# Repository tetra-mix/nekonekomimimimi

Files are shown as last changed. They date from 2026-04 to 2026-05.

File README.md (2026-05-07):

# ねこねこみみみみ
## 概要
VRCとの連携を目的として、市販されている猫耳カチューシャに取り付けられるハプティクスデバイスを作成する。ケーブル部分には、3Dプリンターで作成したケーブルチェーンを用いる。senseshift-hardwareというOSSプロジェクトを参考にしながら作成する。

## 参考
[自作ハプティクスベストを作ってみた。｜KirisameNanoha](https://note.com/kirisamenanoha/n/n8a3842eb5d57)
[GitHub - senseshift/senseshift-hardware: Hardware schematics to build haptic-feedback devices](https://github.com/senseshift/senseshift-hardware)
[OSC](https://note.com/kirisamenanoha/n/n18400ababb78?app_launch=false)
## 予備知識

### ハプティクスモーターについて
ERM 偏心回転質量
* PWAで制御
	種類
	* コイン型
	* 円筒型
	* コア型

LRA 線形共振
* 注意：ドライバが必要
	種類
	* コイン型
	* バー型
	* Y軸(平行)
	* Z軸(垂直)

## 案
### 案１
* マイコン esp32系
	* xiao esp32s3 or c6
* ドライバ DRV2605 x2
* LRAコイン型(Z軸)を直線に複数配置
* 左右の耳の下に3つずつ(計6つ)
* 電源をどうするかは検討
	* リポバッテリー？
	* 最初はモバイルバッテリーかな
→LRAが入手しづらい

### 案２ →採用
 * マイコン esp32系
	* xiao esp32s3 or c6
* ERMコイン型を直線に複数配置
* 左右の耳の下に3つずつ(計6つ)
* MOSFET x6
* 電源をどうするかは検討
	* リポバッテリー？
	* 最初はモバイルバッテリー

## 回路図
1チャンネル分
```
                 VMOTOR (+3.0V～4.2V)
                        |
                        |
                    +---+---+
                    |  ERM  |
                    |Motor  |
                    +---+---+
                        |
                        +-------------------+
                        |                   |
                        |                 |<| D1
                        |            SS14 / 1N5819
                        |                 | |
                        |                   |
                        |                   +---- VMOTOR
                        |
                      Drain
                    Q1 N-MOSFET ---- Gate
                      Source
                        |
                       GND

XIAO GPIO PWM ----[100Ω]---- Gate
                         |
                       [100kΩ]
                         |
                        GND
```

MOSFETをどれだけON・OFFするかによって強さを決める

## 配置図
```
        [前（おでこ）]

   左側               右側
   ●──●──●       ●──●──●
   前  中  後       前  中  後

        [後（後頭部）]
```

## 部品
秋月電子の場合

| 品名 | 型番 |  個数 | 値段 | 購入リンク |
| --- | --- | --: | ----: | --- |
| DMOSトランジスタアレイ | TBD62003APG | 1 | 100 | [109943](https://akizukidenshi.com/catalog/g/g109943/) |
| ミニ振動モーター | (記載なし / 秋月ミニ振動モーター) | 6 | 200 | [16777](https://akizukidenshi.com/catalog/g/g116777/)  |
| マイコンボード | XIAO ESP32S3 | 1 | 1,480 | [118078](https://akizukidenshi.com/catalog/g/g118078/) |
| ショットキーダイオード | 1S4 | 1 | 140 | [116384](https://akizukidenshi.com/catalog/g/g116384/) |
| 電解コンデンサ | 1000µF（耐圧10V〜） | 1 | 20 | [108424](https://akizukidenshi.com/catalog/g/g108424/) |
| LDO 3.3V1A | BA033CC0T | 1 | 100 | [113675](https://akizukidenshi.com/catalog/g/g113675/) |

合計3220円

振動モーターはアリエクで買ってもいいかも？

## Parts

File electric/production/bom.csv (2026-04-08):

Designator | Footprint | Quantity | Value | LCSC Part #
C1 | CP_Radial_D10.0mm_P5.00mm | 1 | 1000u
D1, D2, D3, D4, D5, D6, D7 | D_DO-35_SOD27_P7.62mm_Horizontal | 7 | D
H1, H2, H3, H4 | MountingHole_2.2mm_M2 | 4 | MountingHole
J1, J2, J3, J4, J5, J6, J7 | JST_XH_B2B-XH-A_1x02_P2.50mm_Vertical | 7 | Conn_01x02_Socket
J8 | PinHeader_1x06_P2.54mm_Vertical | 1 | Conn_01x06
R1, R2, R3, R4, R5, R6, R7 | resistor_0207_10 | 7 | 100
R10, R11, R12, R13, R14, R8, R9 | resistor_0207_10 | 7 | 100k
U1 | XIAO-ESP32-C6-DIP | 1 | XIAO-ESP32-C3-DIP
U2 | DIP-16_W7.62mm_Socket | 1 | TBD62003APG
U3 | PinHeader_1x03_P2.54mm_Vertical | 1 | BP5293

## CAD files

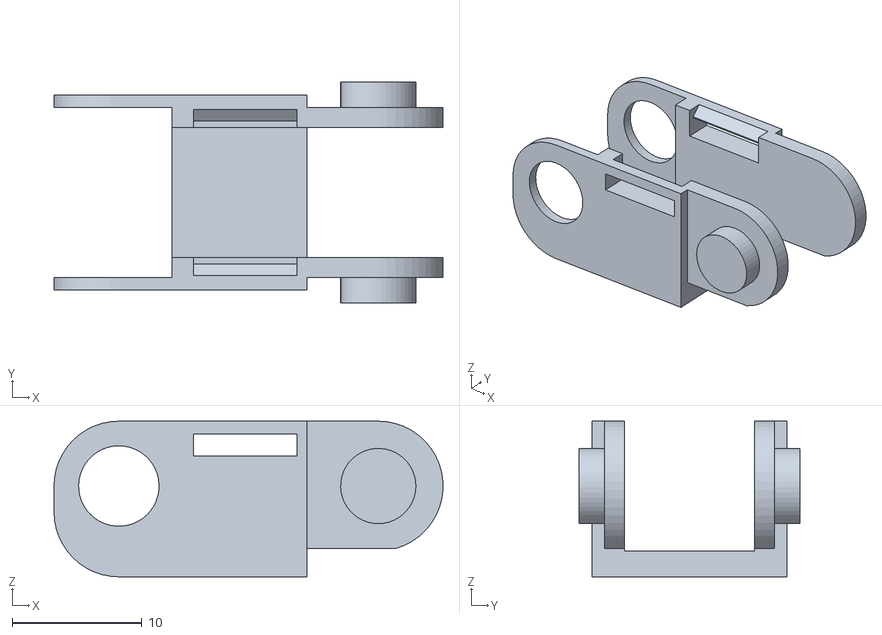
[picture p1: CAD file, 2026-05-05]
3Dmodel/vr2.0_CableChane_Original.stl
30.0 x 17.0 x 12.0

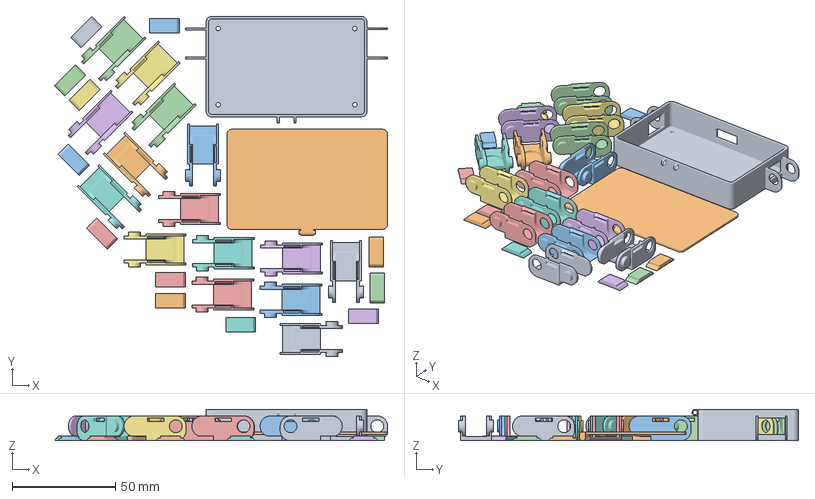
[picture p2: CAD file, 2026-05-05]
3Dmodel/vr1.1_CableChane.3mf
161.0 x 164.3 x 15.2 mm
PCBCase_base.stl
PCBCase_top.stl
CableChane_Original.stl x 9
CableChane_Motor.stl x 6
CaseTop.stl x 12

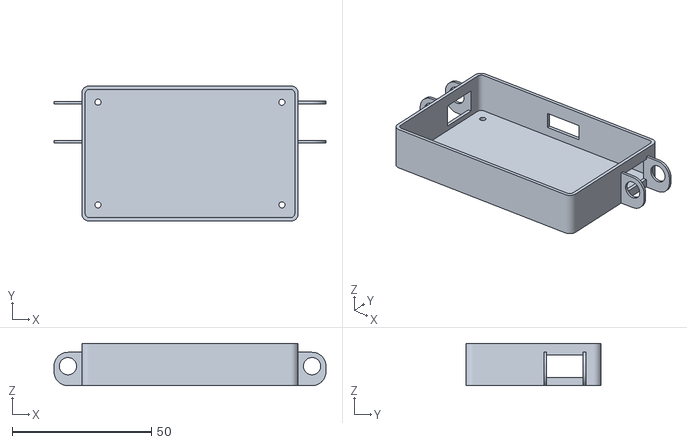
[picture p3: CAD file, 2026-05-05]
3Dmodel/vr2.0_PCBCase_base.stl
97.6 x 48.4 x 15.2

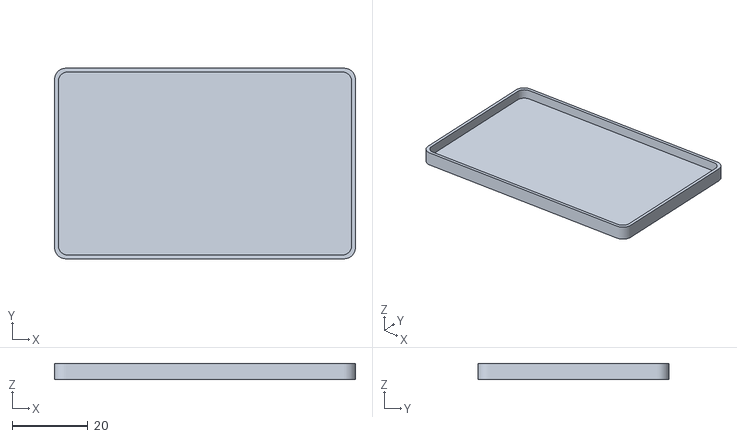
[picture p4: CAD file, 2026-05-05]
3Dmodel/vr2.0_PCBCase_top.stl
79.7 x 50.4 x 4.30

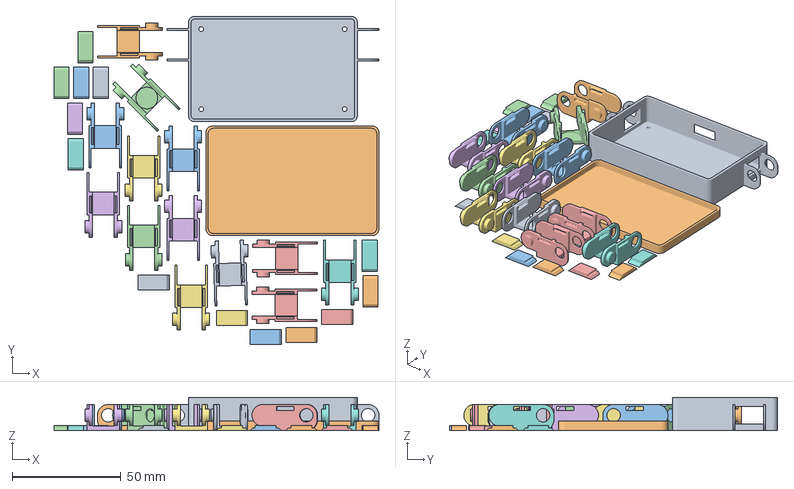
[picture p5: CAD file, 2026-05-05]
3Dmodel/vr2.0_CableChane_Motor.3mf
149.6 x 151.0 x 15.2 mm
vr2.0_PCBCase_base.stl
vr2.0_PCBCase_top.stl
vr2.0_CableChane_Motor.stl x 7
vr2.0_CableChane_Original.stl x 6
vr1.1_ChaneTop.stl x 13

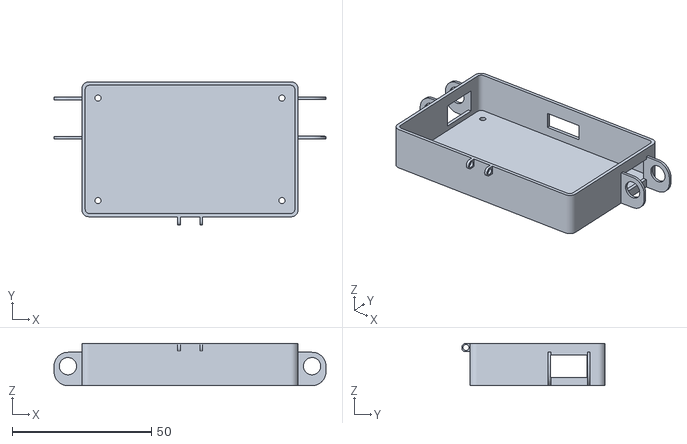
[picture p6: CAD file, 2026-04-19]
3Dmodel/vr1.0_PCBCase_base.stl
97.6 x 51.4 x 15.2

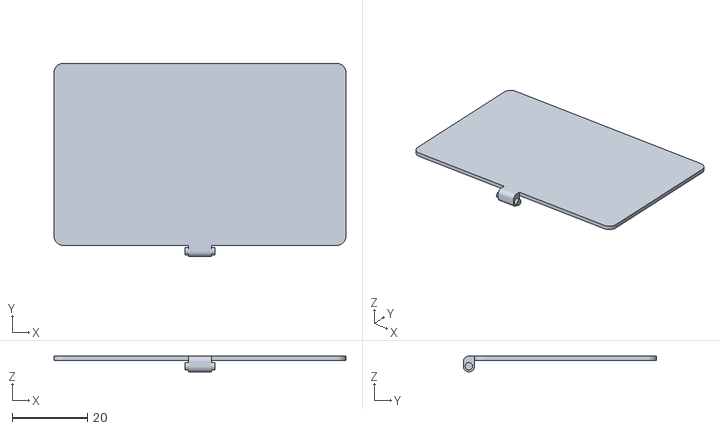
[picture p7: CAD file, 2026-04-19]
3Dmodel/vr1.0_PCBCase_top.stl
77.7 x 51.4 x 4.20

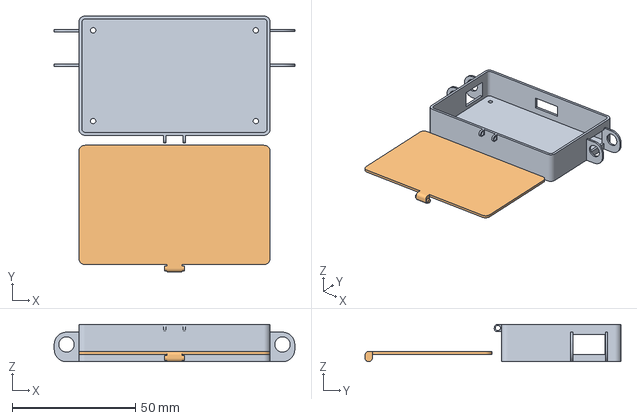
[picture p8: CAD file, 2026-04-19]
3Dmodel/vr1.0_PCBCase.3mf
97.6 x 103.9 x 15.2 mm
PCBCase_base.stl
PCBCase_top.stl

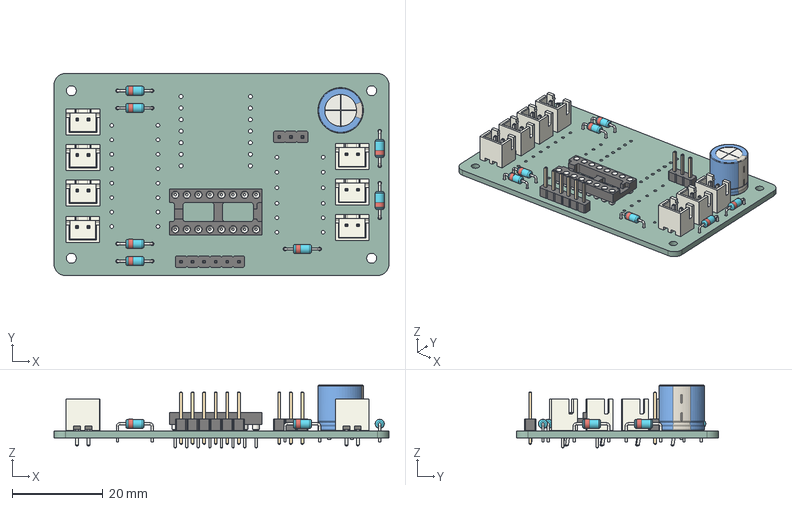
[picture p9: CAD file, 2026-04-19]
3Dmodel/PCB.step
73.7 x 44.5 x 13.8 mm
D_DO-35_SOD27_P7.62mm_Horizontal x 7
PinHeader_1x06_P2.54mm_Vertical
JST_XH_B2B-XH-A_1x02_P2.50mm_Vertical x 7
PinHeader_1x03_P2.54mm_Vertical
DIP-16_W7.62mm_Socket
CP_Radial_D10.0mm_P5.00mm
nekonekomimimimi_PCB

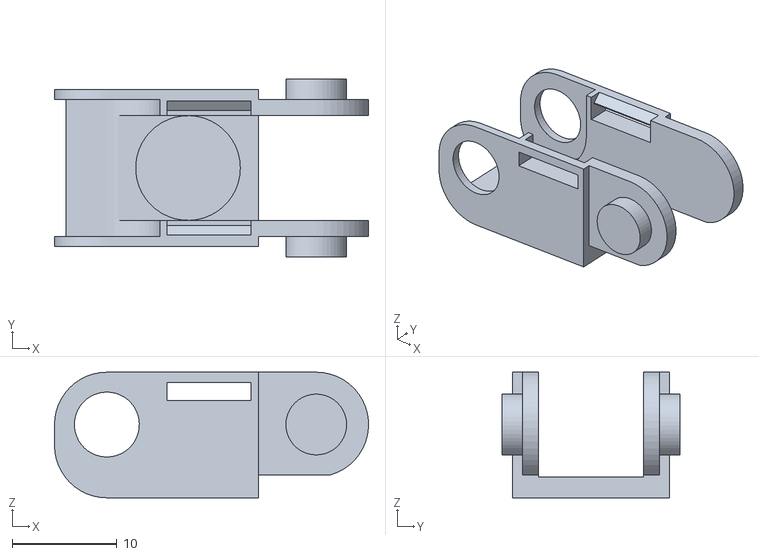
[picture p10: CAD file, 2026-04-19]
3Dmodel/vr1.1_CableChane_Motor.stl
30.0 x 17.0 x 12.0

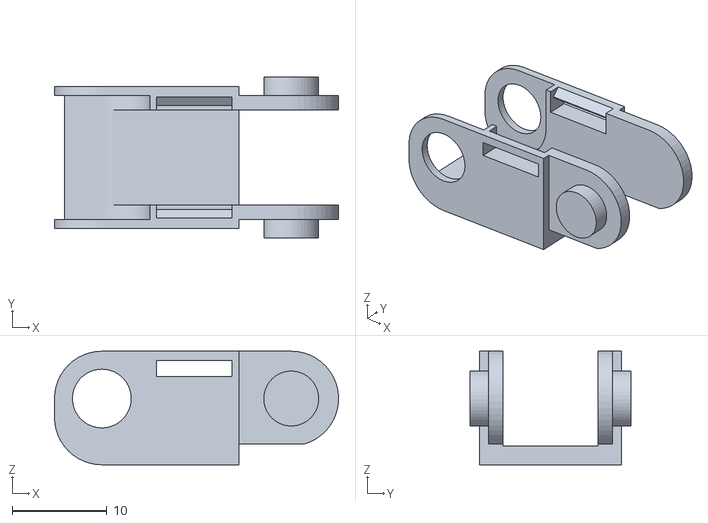
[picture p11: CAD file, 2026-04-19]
3Dmodel/vr1.1_CableChane_Original.stl
30.0 x 17.0 x 12.0

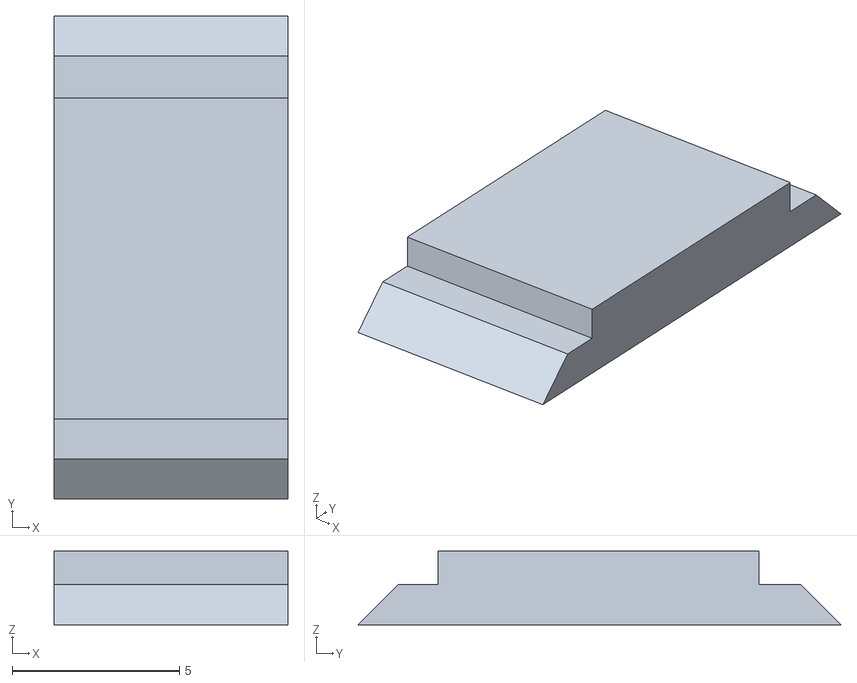
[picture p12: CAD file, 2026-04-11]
3Dmodel/vr1.1_ChaneTop.stl
7.00 x 14.4 x 2.20

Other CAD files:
3Dmodel/vr1.1_CableChane.gcode.3mf
3Dmodel/vr1.0_PCBCase.gcode.3mf
3Dmodel/vr2.0_CableChane_Motor.stl

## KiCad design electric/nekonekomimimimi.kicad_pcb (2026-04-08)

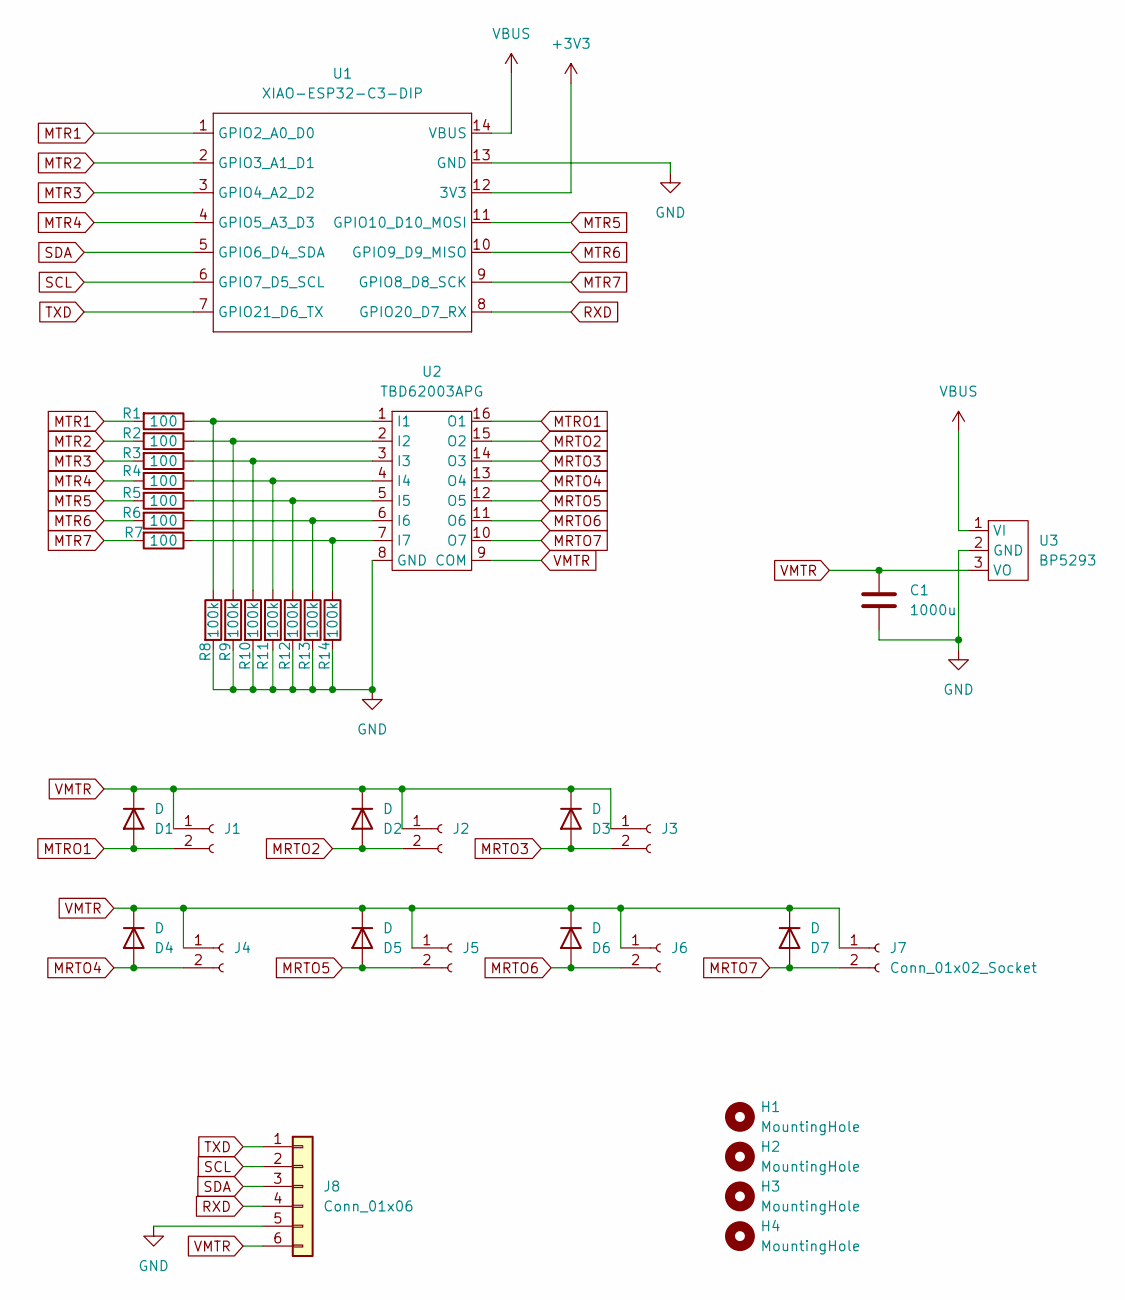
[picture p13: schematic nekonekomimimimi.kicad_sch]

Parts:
C1: 1000u; CP_Radial_D10.0mm_P5.00mm
D1, D2, D3, D4, D5, D6, D7: D; D_DO-35_SOD27_P7.62mm_Horizontal
H1, H2, H3, H4: MountingHole; MountingHole_2.2mm_M2
J1, J2, J3, J4, J5, J6, J7: Conn_01x02_Socket; JST_XH_B2B-XH-A_1x02_P2.50mm_Vertical
J8: Conn_01x06; PinHeader_1x06_P2.54mm_Vertical
R1, R2, R3, R4, R5, R6, R7: 100; resistor_0207_10
R8, R9, R10, R11, R12, R13, R14: 100k; resistor_0207_10
U1: XIAO-ESP32-C3-DIP; XIAO-ESP32-C6-DIP
U2: TBD62003APG; DIP-16_W7.62mm_Socket
U3: BP5293; PinHeader_1x03_P2.54mm_Vertical

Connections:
+3V3: U1.12 (3V3)
GND: C1.2, J8.5, R8.2, R9.2, R10.2, R11.2, R12.2, R13.2, R14.2, U1.13 (GND), U2.8 (GND), U3.2 (GND)
MRTO2: D2.2 (A), J2.2, U2.15 (O2)
MRTO3: D3.2 (A), J3.2, U2.14 (O3)
MRTO4: D4.2 (A), J4.2, U2.13 (O4)
MRTO5: D5.2 (A), J5.2, U2.12 (O5)
MRTO6: D6.2 (A), J6.2, U2.11 (O6)
MRTO7: D7.2 (A), J7.2, U2.10 (O7)
MTR1: R1.2, U1.1 (GPIO2_A0_D0)
MTR2: R2.2, U1.2 (GPIO3_A1_D1)
MTR3: R3.2, U1.3 (GPIO4_A2_D2)
MTR4: R4.2, U1.4 (GPIO5_A3_D3)
MTR5: R5.2, U1.11 (GPIO10_D10_MOSI)
MTR6: R6.2, U1.10 (GPIO9_D9_MISO)
MTR7: R7.2, U1.9 (GPIO8_D8_SCK)
MTRO1: D1.2 (A), J1.2, U2.16 (O1)
unnamed: R1.1, R8.1, U2.1 (I1)
unnamed: R2.1, R9.1, U2.2 (I2)
unnamed: R3.1, R10.1, U2.3 (I3)
unnamed: R4.1, R11.1, U2.4 (I4)
unnamed: R5.1, R12.1, U2.5 (I5)
unnamed: R6.1, R13.1, U2.6 (I6)
unnamed: R7.1, R14.1, U2.7 (I7)
RXD: J8.4, U1.8 (GPIO20_D7_RX)
SCL: J8.2, U1.6 (GPIO7_D5_SCL)
SDA: J8.3, U1.5 (GPIO6_D4_SDA)
TXD: J8.1, U1.7 (GPIO21_D6_TX)
VBUS: U1.14 (VBUS), U3.1 (VI)
VMTR: C1.1, D1.1 (K), D2.1 (K), D3.1 (K), D4.1 (K), D5.1 (K), D6.1 (K), D7.1 (K), J1.1, J2.1, J3.1, J4.1, J5.1, J6.1, J7.1, J8.6, U2.9 (COM), U3.3 (VO)

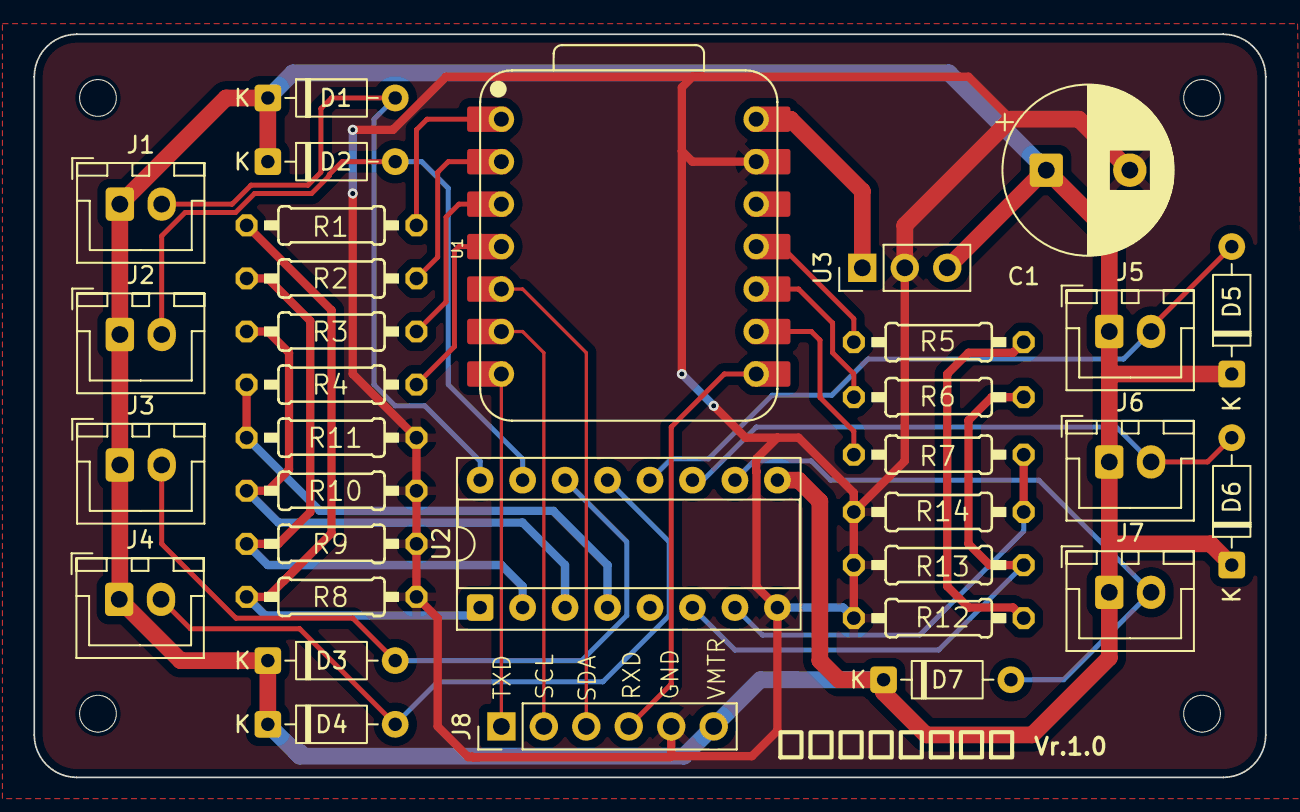
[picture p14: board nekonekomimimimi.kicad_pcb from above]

Board: 2 copper layers, 73.7 x 44.5 mm, 37 parts (0 on the bottom side), 28 nets.

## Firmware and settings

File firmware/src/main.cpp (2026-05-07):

#include <Arduino.h>
#include <ArduinoOSCWiFi.h>
#include <WiFi.h>

#define ESP_WM_LITE_DEBUG_OUTPUT Serial
#define _ESP_WM_LITE_LOGLEVEL_ 2
// The board pins used for the motors overlap typical status LED defaults.
#define USE_LED_BUILTIN false
// Accept a single Wi-Fi credential pair in the config portal.
#define REQUIRE_ONE_SET_SSID_PW true

#include <ESP_WiFiManager_Lite.h>
#include "motor_control.h"
#include "osc_router.h"

bool LOAD_DEFAULT_CONFIG_DATA = false;

ESP_WM_LITE_Configuration defaultConfig = {
  "ESP32",
  {
    {"", ""},
    {"", ""}
  },
  "hard-osc",
  0
};

uint32_t getChipID() {
  uint64_t chipId64 = 0;

  for (int i = 0; i < 6; ++i) {
    chipId64 |= (((uint64_t)ESP.getEfuseMac() >> (40 - (i * 8))) & 0xff) << (i * 8);
  }

  return static_cast<uint32_t>(chipId64 & 0xFFFFFF);
}

uint32_t getChipOUI() {
  uint64_t chipId64 = 0;

  for (int i = 0; i < 6; ++i) {
    chipId64 |= (((uint64_t)ESP.getEfuseMac() >> (40 - (i * 8))) & 0xff) << (i * 8);
  }

  return static_cast<uint32_t>(chipId64 >> 24);
}

namespace {

constexpr int kOscRecvPort = 9001;
constexpr char kHostName[] = "hard-osc";
constexpr char kConfigPortalSsid[] = "hard-osc-setup";
constexpr char kConfigPortalPassword[] = "00000000";

ESP_WiFiManager_Lite* wifiManager = nullptr;
bool lastConfigMode = false;

void setupWiFiManager() {
  wifiManager = new ESP_WiFiManager_Lite();
  wifiManager->setConfigPortal(kConfigPortalSsid, kConfigPortalPassword);
  wifiManager->setConfigPortalChannel(0);
  wifiManager->begin(kHostName);

  if (WiFi.status() == WL_CONNECTED) {
    Serial.print("[wifi] connected, STA IP: ");
    Serial.println(WiFi.localIP());
  } else if (wifiManager->isConfigMode()) {
    Serial.print("[wifi] config portal active: ");
    Serial.println(kConfigPortalSsid);
  }
}

void updateWiFiManager() {
  wifiManager->run();

  const bool configMode = wifiManager->isConfigMode();
  if (configMode != lastConfigMode) {
    lastConfigMode = configMode;

    if (configMode) {
      Serial.print("[wifi] entered config portal: ");
      Serial.println(kConfigPortalSsid);
    } else if (WiFi.status() == WL_CONNECTED) {
      Serial.print("[wifi] connected, STA IP: ");
      Serial.println(WiFi.localIP());
    }
  }
}

}  // namespace

void setup() {
  Serial.begin(115200);
  delay(200);

  initMotors();
  stopAllMotors();

  setupWiFiManager();
  subscribeOscRoutes(kOscRecvPort);

  Serial.printf("[osc] listening on UDP %d\n", kOscRecvPort);
  Serial.println("[osc] routes: /motor/1..7, /motor/all, /motor/stop");
}

void loop() {
  updateWiFiManager();
  OscWiFi.update();
  updateMotorFailsafe();
  delay(0);
}

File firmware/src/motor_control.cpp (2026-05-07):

#include "motor_control.h"

#include <Arduino.h>
#include <esp32-hal-ledc.h>

namespace {

constexpr unsigned long kOscTimeoutMs = 1000;
constexpr uint32_t kPwmFrequencyHz = 10000;
constexpr uint8_t kPwmResolutionBits = 8;
constexpr uint32_t kPwmMaxDuty = (1u << kPwmResolutionBits) - 1u;

constexpr int kMotorPins[kMotorCount] = {
  2,   // ch1 -> GPIO2 / D0
  3,   // ch2 -> GPIO3 / D1
  4,   // ch3 -> GPIO4 / D2
  5,   // ch4 -> GPIO5 / D3
  10,  // ch5 -> GPIO10 / D10
  9,   // ch6 -> GPIO9 / D9
  8    // ch7 -> GPIO8 / D8
};

constexpr int kPwmChannels[kMotorCount] = {0, 1, 2, 3, 4, 5, 6};

float motorLevels[kMotorCount] = {0.0f};
unsigned long lastOscReceivedMs = 0;
bool oscFailsafeTriggered = false;

float clampLevel(float value) {
  if (value < 0.0f) return 0.0f;
  if (value > 1.0f) return 1.0f;
  return value;
}

uint32_t levelToDuty(float level) {
  const float clamped = clampLevel(level);
  return static_cast<uint32_t>(clamped * static_cast<float>(kPwmMaxDuty) + 0.5f);
}

void applyMotorLevelToHardware(size_t index, float level) {
  ledcWrite(kMotorPins[index], levelToDuty(level));
}

}  // namespace

void initMotors() {
  for (size_t i = 0; i < kMotorCount; ++i) {
    pinMode(kMotorPins[i], OUTPUT);
    ledcAttachChannel(kMotorPins[i], kPwmFrequencyHz, kPwmResolutionBits, kPwmChannels[i]);
    ledcWrite(kMotorPins[i], 0);
    motorLevels[i] = 0.0f;
  }
}

void setMotorLevel(size_t index, float level) {
  if (index >= kMotorCount) {
    return;
  }

  const float clamped = clampLevel(level);
  motorLevels[index] = clamped;
  applyMotorLevelToHardware(index, clamped);

  Serial.printf("[motor] ch%u = %.3f\n", static_cast<unsigned>(index + 1), clamped);
}

void stopAllMotors() {
  for (size_t i = 0; i < kMotorCount; ++i) {
    motorLevels[i] = 0.0f;
    applyMotorLevelToHardware(i, 0.0f);
  }

  Serial.println("[motor] all stop");
}

void markOscReceived() {
  lastOscReceivedMs = millis();
  oscFailsafeTriggered = false;
}

void updateMotorFailsafe() {
  if (lastOscReceivedMs == 0 || oscFailsafeTriggered) {
    return;
  }

  if (millis() - lastOscReceivedMs < kOscTimeoutMs) {
    return;
  }

  stopAllMotors();
  oscFailsafeTriggered = true;
  Serial.println("[motor] failsafe stop: OSC timeout");
}

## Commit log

2026-04-08 feat: electric
    [nekonekomimimimi.kicad_pcb, nekonekomimimimi.kicad_sch]
2026-04-08 update: build data
    [bom.csv, designators.csv, positions.csv]
2026-04-08 update: 3D files
    [CableChane_Motor.stl, CableChane_Original.stl]
2026-04-11 feat: 3D models
    [CableChane_Motor.3mf, CableChane_Motor.stl, CableChane_Original.stl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]
2026-04-19 faet: add 3D models
    [CableChane.3mf, CableChane.gcode.3mf, CableChane_Motor.3mf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]
2026-05-05 update: add 3Dmodels
    [CableChane.3mf, vr1.0_PCBCase.3mf, vr1.0_PCBCase.gcode.3mf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]
